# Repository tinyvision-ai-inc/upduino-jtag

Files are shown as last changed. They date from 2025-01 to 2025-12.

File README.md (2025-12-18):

# JTAG translator using UPduino

We have an FTDI FT232 on the UPduino which is what is typically used in various JTAG debuggers. The ICE40 FPGA enables level translation as well as a UART interface which is typically used for debugging.

## Connections:
1. Cut the Bank 2 VIO sel jumper and short it to VIO. This allows the FPGA bank to be powered from the VIO pin which can be set to the VREF signal from the JTAG port.
2. Make the following connections:

  | Signal | Pin     |
  |--------|---------|
  | TCK    | gpio_2  |
  | TDI    | gpio_47 |
  | TDO    | gpio_46 |
  | TMS    | gpio_45 |
  | RXD    | gpio_48 |
  | TXD    | gpio_3  |
  | RSTn   | gpio_4  |
  | Ground | Ground  |
  | VIO    | VREF    |

In case the target is a 1.8V system, a cheap way to avoid the VREF line is to use a resistive voltage divider to source the VIO pin. This isnt optimal but should work since the power draw from the IO is pretty small. Use 2 470 ohm resistors to divide the 3.3V which will result in 1.65V as the logic level, not ideal but close.

Mapping to the FPGA pins:

| Pin | Signal | Pin | Signal |
|-----|---|-----|---|
| 1 | Vref | 2 | TMS (45) |
| 3 | GND | 4 | TCK (2) |
| 5 | GND | 6 | TDO (46) |
| 7 | TXD | 8 | TDI (47) |
| 9 | RXD | 10  | RSTn (4) |

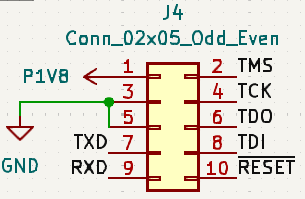
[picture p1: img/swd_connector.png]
Signals mapped to the SWD connector


## Selection between UART and JTAG

There appears to be no way to select between when the FTDI wants to use its IO as JTAG vs. UART. Rather than being clever about it, we can simply use a manual jumper for this.

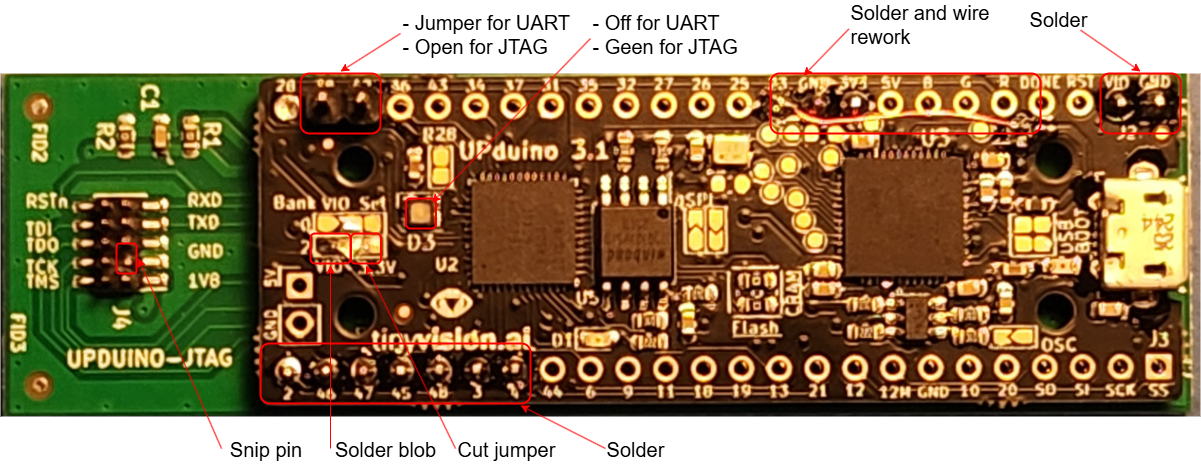
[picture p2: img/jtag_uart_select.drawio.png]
JTAG vs UART selection Jumper


`gpio_42` is setup as a `JTAG_SELECT` pin and a 10K pullups is added to this pin in the FPGA constraints file. `gpio_38` is set low in the FPGA.

- UART mode: Add jumper between `gpio_38` and `gpio_42`. The green LED on the UPduino goes `OFF` indicate this.
- JTAG MODE: Remove jumper between `gpio_38` and `gpio_42`. The green LED on the UPduino comes `ON` to indicate this.

## Pogo probe adapter

While its nice to have a standard 10 pin JTAG connector, this takes up significant board space. By moving these pins to a series of pads, we can save space. Alterntively, these can be moved as castellations on the edge of the board to save even more space.

A pogo probe connector such as [854-22-006-20-041101 from Millmax](https://www.digikey.com/en/products/detail/mill-max-manufacturing-corp/854-22-006-20-041101/24634760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) makes a robust way to connect to the debug pads.

Pogo connector

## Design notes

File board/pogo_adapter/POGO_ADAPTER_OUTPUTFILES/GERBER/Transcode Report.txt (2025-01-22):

   ---- Transcoding 'E:\Works\BibinCJoseph\UPDUINO_JTAG\upduino-jtag\upduino-jtag\board\pogo_adapter\GERBER\pogo_adapter-F_Silkscreen.gbr' ----   Wed Jan 22 12:11:26 2025

D10   --> D100
D11   --> D101
D12   --> D102
D13   --> D103
-----------------------------------------------------------------

   ---- Transcoding 'E:\Works\BibinCJoseph\UPDUINO_JTAG\upduino-jtag\upduino-jtag\board\pogo_adapter\GERBER\pogo_adapter-F_Paste.gbr' ----   Wed Jan 22 12:11:26 2025

D10   --> D104
D11   --> D105
-----------------------------------------------------------------

   ---- Transcoding 'E:\Works\BibinCJoseph\UPDUINO_JTAG\upduino-jtag\upduino-jtag\board\pogo_adapter\GERBER\pogo_adapter-F_Mask.gbr' ----   Wed Jan 22 12:11:26 2025

D10   --> D106
D11   --> D107
D12   --> D108
D13   --> D109
D14   --> D110
-----------------------------------------------------------------

   ---- Transcoding 'E:\Works\BibinCJoseph\UPDUINO_JTAG\upduino-jtag\upduino-jtag\board\pogo_adapter\GERBER\pogo_adapter-F_Cu.gbr' ----   Wed Jan 22 12:11:26 2025

D10   --> D111
D11   --> D112
D12   --> D113
D13   --> D114
D14   --> D115
D15   --> D116
-----------------------------------------------------------------

   ---- Transcoding 'E:\Works\BibinCJoseph\UPDUINO_JTAG\upduino-jtag\upduino-jtag\board\pogo_adapter\GERBER\pogo_adapter-Edge_Cuts.gbr' ----   Wed Jan 22 12:11:26 2025

D10   --> D117
-----------------------------------------------------------------

   ---- Transcoding 'E:\Works\BibinCJoseph\UPDUINO_JTAG\upduino-jtag\upduino-jtag\board\pogo_adapter\GERBER\pogo_adapter-drl_map.gbr' ----   Wed Jan 22 12:11:26 2025

D10   --> D118
D11   --> D119
D12   --> D120
D13   --> D121
-----------------------------------------------------------------

   ---- Transcoding 'E:\Works\BibinCJoseph\UPDUINO_JTAG\upduino-jtag\upduino-jtag\board\pogo_adapter\GERBER\pogo_adapter-B_Mask.gbr' ----   Wed Jan 22 12:11:26 2025

D10   --> D122
D11   --> D123
D12   --> D124
D13   --> D125
-----------------------------------------------------------------

   ---- Transcoding 'E:\Works\BibinCJoseph\UPDUINO_JTAG\upduino-jtag\upduino-jtag\board\pogo_adapter\GERBER\pogo_adapter-B_Cu.gbr' ----   Wed Jan 22 12:11:26 2025

D10   --> D126
D11   --> D127
D12   --> D128
D13   --> D129
D14   --> D130
-----------------------------------------------------------------

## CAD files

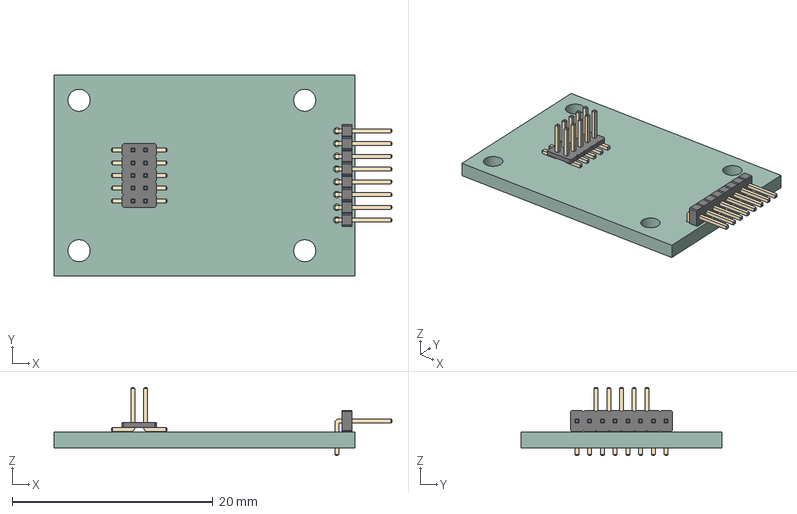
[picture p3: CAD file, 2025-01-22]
board/pogo_adapter/POGO_ADAPTER_OUTPUTFILES/STEP/pogo_adapter.step
33.7 x 20.0 x 6.80 mm
PinHeader_1x08_P127mm_Horizontal
PinHeader_2x05_P127mm_Vertical_SMD
pogo_adapter_PCB

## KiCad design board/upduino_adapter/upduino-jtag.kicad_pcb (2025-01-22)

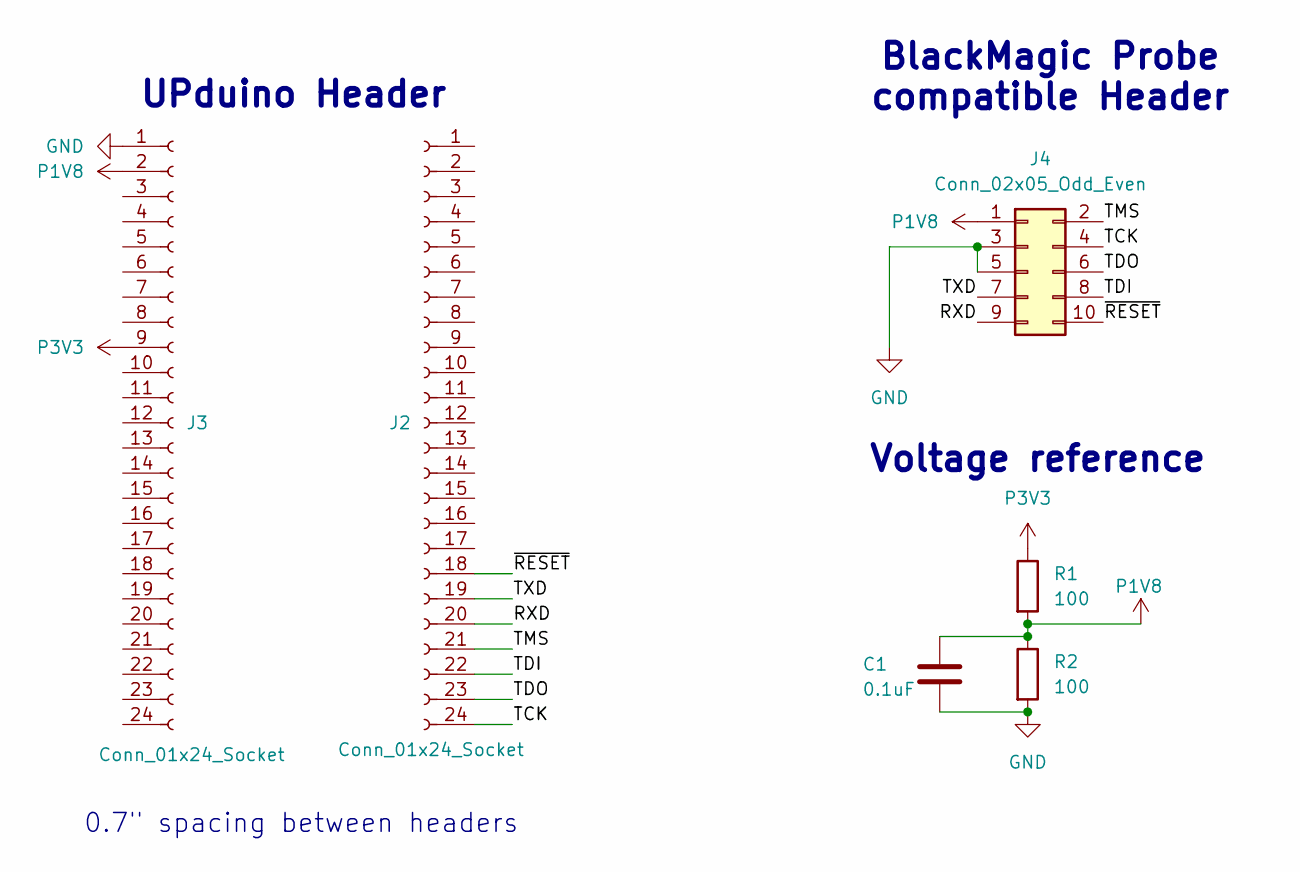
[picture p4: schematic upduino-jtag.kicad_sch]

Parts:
C1: 0.1uF; C_0603_1608Metric_Pad1.08x0.95mm_HandSolder
J2, J3: Conn_01x24_Socket; PinHeader_1x24_P2.54mm_Vertical
J4: Conn_02x05_Odd_Even; PinHeader_2x05_P1.27mm_Vertical_SMD
R1, R2: 100; R_0603_1608Metric_Pad0.98x0.95mm_HandSolder

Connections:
/RXD: J2.20, J4.9
/TCK: J2.24, J4.4
/TDI: J2.22, J4.8
/TDO: J2.23, J4.6
/TMS: J2.21, J4.2
/TXD: J2.19, J4.7
/~RESET: J2.18, J4.10
GND: C1.2, J3.1, J4.3, J4.5, R2.2
P1V8: C1.1, J3.2, J4.1, R1.2, R2.1
P3V3: J3.9, R1.1

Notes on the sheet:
BlackMagic Probe compatible Header
0.7" spacing between headers
UPduino Header
Voltage reference

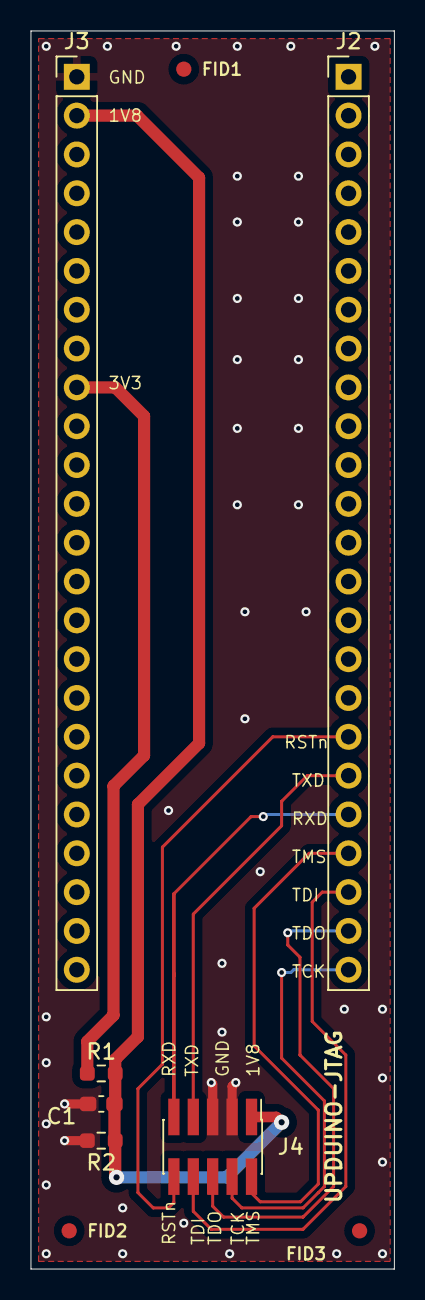
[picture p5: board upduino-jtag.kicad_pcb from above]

Board: 2 copper layers, 23.8 x 81.0 mm, 9 parts (0 on the bottom side), 10 nets.

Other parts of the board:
FID1, FID2, FID3: Fiducial_1mm_Mask2mm

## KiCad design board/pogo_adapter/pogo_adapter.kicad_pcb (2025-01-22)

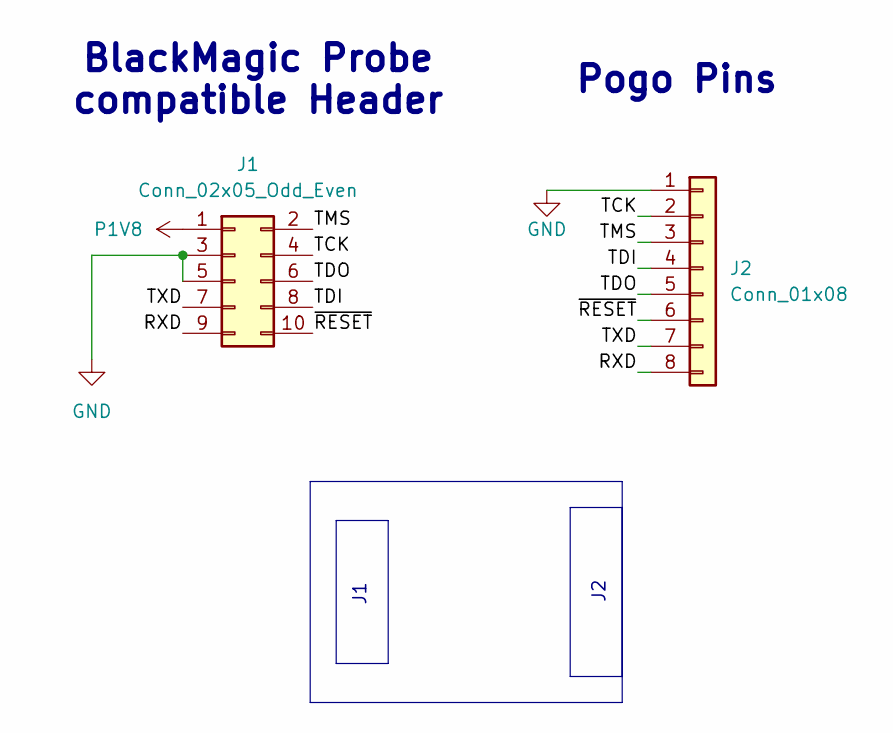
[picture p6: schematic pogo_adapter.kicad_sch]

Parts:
J1: Conn_02x05_Odd_Even; PinHeader_2x05_P1.27mm_Vertical_SMD
J2: Conn_01x08; PinHeader_1x08_P1.27mm_Horizontal

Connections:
/RXD: J1.9, J2.8
/TCK: J1.4, J2.2
/TDI: J1.8, J2.4
/TDO: J1.6, J2.5
/TMS: J1.2, J2.3
/TXD: J1.7, J2.7
/~RESET: J1.10, J2.6
GND: J1.3, J1.5, J2.1
P1V8: J1.1

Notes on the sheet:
Pogo Pins
BlackMagic Probe compatible Header

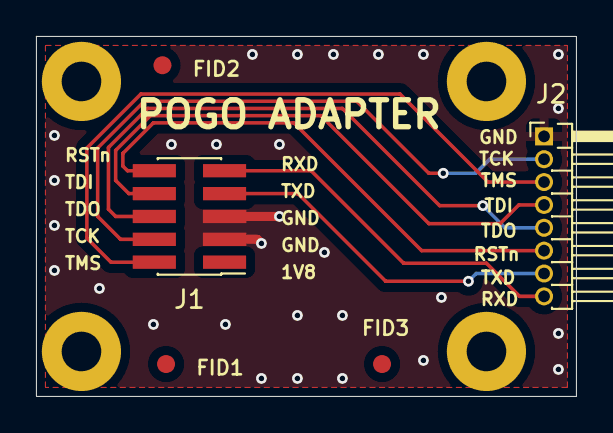
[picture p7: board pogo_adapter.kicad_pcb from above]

Board: 2 copper layers, 30.0 x 20.0 mm, 9 parts (0 on the bottom side), 8 nets.

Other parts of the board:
FID1, FID2, FID3: Fiducial_1mm_Mask2mm
M1, M2, M3, M4: MountingHole_2.2mm_M2_Pad

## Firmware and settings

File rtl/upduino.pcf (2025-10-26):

# The LED pins are on dedicated pins and cannot be modified!
# Note that they are negative logic (write a 0 to turn on).
# These are also brought out to the left side of the board. 
# Cut the board trace on jumper R28 to disable the onboard 3 color LED.
set_io -nowarn led_green 39
set_io -nowarn led_red	41
set_io -nowarn led_blue	40

# FTDI chip interface
set_io -nowarn serial_txd 14 # FPGA transmit to USB
set_io -nowarn serial_rxd 15 # FPGA receive from USB
set_io -nowarn -pullup_resistor 10K spi_cs 16 # Connected to SPI flash, drive high unless using SPI flash!

# If using the FTDI MPSSE engine, the following signals apply
set_io -nowarn spi_sck 15  # Shared with the flash
set_io -nowarn -pullup_resistor 10K spi_ssn 16  # Connected to SPI flash, drive high unless using SPI flash!
set_io -nowarn -pullup_resistor 10K spi_mosi 17 # Shared with the flash
set_io -nowarn -pullup_resistor 10K spi_miso 14 # Shared with the flash

# Normal GPIO pins, left side
set_io -nowarn gpio_23 23
set_io -nowarn gpio_25 25
set_io -nowarn gpio_26 26
set_io -nowarn gpio_27 27
set_io -nowarn gpio_32 32
set_io -nowarn gpio_35 35
set_io -nowarn gpio_31 31
set_io -nowarn gpio_37 37
set_io -nowarn gpio_34 34
set_io -nowarn gpio_43 43
set_io -nowarn gpio_36 36
#set_io -nowarn -pullup_resistor 10K gpio_42 42 # Pullup will get pulled down by the jumper
set_io -nowarn gpio_38 38
set_io -nowarn gpio_28 28


# Normal GPIO pins, right side

# Following pins are added on the v3.0 of the board.
# SPI pins are brought out to the right side of the board

# Note: On board 12MHz clock can be brought to IOB_25B_G3 (pin 20) which is a global
# clock input. Short across R16 (labelled OSC on the board) to enable 12MHz clock to
# pin 20.
set_io -nowarn gpio_20 20
set_io -nowarn gpio_10 10

# Following are also found on v2.x of the UPduino
set_io -nowarn gpio_12 12
set_io -nowarn gpio_21 21
set_io -nowarn gpio_13 13
set_io -nowarn gpio_19 19
set_io -nowarn gpio_18 18
set_io -nowarn gpio_11 11
set_io -nowarn gpio_9 9
set_io -nowarn gpio_6 6
set_io -nowarn gpio_44 44
set_io -nowarn gpio_4 4
set_io -nowarn gpio_3 3
#set_io -nowarn gpio_48 48
set_io -nowarn -pullup_resistor 10K gpio_45 45
set_io -nowarn -pullup_resistor 10K gpio_46 46
set_io -nowarn -pullup_resistor 10K gpio_47 47
set_io -nowarn -pullup_resistor 10K gpio_2 2
set_io -nowarn -pullup_resistor 10K gpio_42 42
set_io -nowarn -pullup_resistor 10K gpio_48 48

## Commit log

2025-01-20 Added schematic
    [upduino-jtag.kicad_pcb, upduino-jtag.kicad_sch]
2025-01-20 Added pogo adapter
    [pogo_adapter.kicad_pcb, pogo_adapter.kicad_sch, upduino-jtag.kicad_pcb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]
2025-01-20 Added details of pogo probe to readme
2025-01-22 updated design files and output files
    [pogo_adapter-B_Cu.gbr, pogo_adapter-B_Mask.gbr, pogo_adapter-Edge_Cuts.gbr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]
2025-10-26 Added UART functionality and tested to wrok
2025-12-18 Added docs for UART vs JTAG selection
